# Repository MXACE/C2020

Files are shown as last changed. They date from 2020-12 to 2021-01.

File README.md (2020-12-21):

# C2020
Christmas Project and for the JLCPCB contest (https://jlcpcb.com).

The project was made with altium.
It is a christmas tree with a holder that you can break of the pcb.
The ic on this pcb is designed the way, that they look like they were presents under the.

On the backside of the tree there will be mounted some reverse RGB LEDs that are controlled by a RGB driver over i2c.

I made this for some friends and familymember as a gift.

You can view some pictures of the pcb if you open schematics.pdf. I didnt received the pcb yet.

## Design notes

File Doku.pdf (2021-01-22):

TBZ | Marco Stauber

# Weihnachtsprojekt

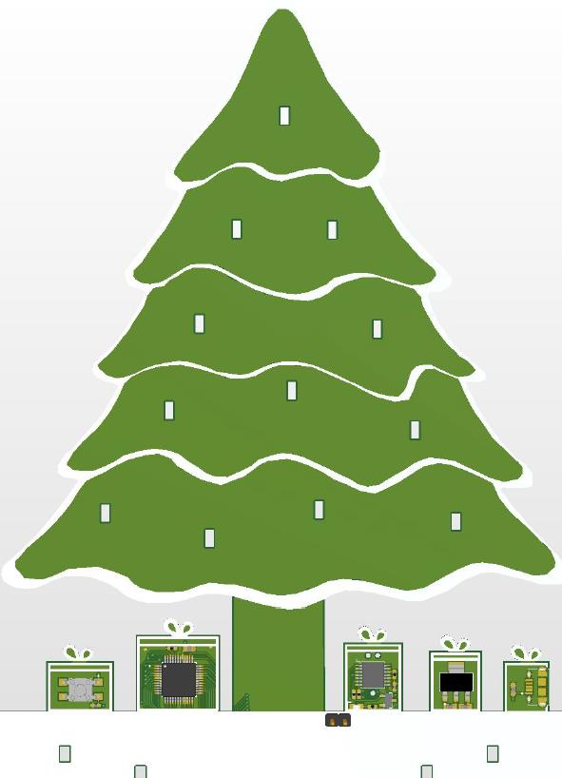
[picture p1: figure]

## Inhaltsverzeichnis

## Idee

Ich wollte für Weihnachten 2020 ein spezielles Geschenk an Familie und Bekannte machen. Eins das von mir kommt. Gleichzeitig hat JLCPCB einen Wettbewerb gestartet, bei dem man ein PCB designen muss das einen Festlichen Stil hat. Dabei kam ich auf die Idee einen Weihnachtsbaum zu zeichnen unter welchem sich Geschenke befinden und darin sind die grossen Bauteile. Als nächstes entschied ich mich dafür dass LEDs die
Weihnachtsbaumkugeln simulieren sollten.

## Umsetzung

### Schema

Ich habe mir eine Skizze vom Baum gemacht und überlegt wie viele und wie ich die LEDs verteilen will. Optimal sind es bei dieser Grösse 12. Um auch schöne Animationen zu gestalten brauchte ich RGB LEDs und für den optischen Pluspunkt Reverse LEDs, die durch kleine Löcher im PCB, durchscheinen können.

Um nicht Tausend RGB Treiber haben zu müssen, nahm ich gleich einen mit 36 Kanälen. Dieser kann man über I2C ansteuern. Er hat für jeden Kanal ein PWM Register und noch weitere Einstellungen.
Das Interessante an diesem Bauteil ist, dass der Pin für die Slave-Adresse 2 Bits entsprechen.

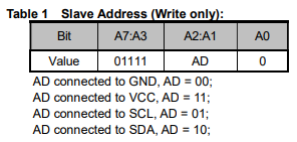
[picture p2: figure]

Das PCB wird über einen USB Mikro Anschluss versorgt. Die heutigen Geräte haben meistens einen USB C Anschluss. Zunächst wollte ich auch eine USB C Buchse nehmen, aber da meine Verwandtschaft eher noch ältere Geräte haben, haben sie auch noch ein paar alte USB Mikro Kabel herumliegen.
Über einen Linearregler kriegt man eine 3.3V Speisung.

Einen Taster ermöglicht das Wechseln zwischen verschiedenen Animationen. Jedoch habe ich nicht gesehen dass der gleiche Pin vom Mikrokontroller, an dem er angeschlossen ist, auch BOOT0 ist. Dieser Fehler hat mich einige Nerven gekostet und konnte es später aber herausfinden. Parallel zum Stütz-Kondensator gibt es jetzt einen 10kOhm Widerstand.

Da ich fast nichts steuern muss, brauchte ich nur einen ganz kleinen Mikrokontroller, welcher ein TSSOP-14 Gehäuse hat. Programmieren tue ich ihn über einen TagConnect Footprint welcher ich zum ersten Mal benutze. Zusätzlich gibt es noch ein LED welches mir noch über das Programm, einen Status geben kann.

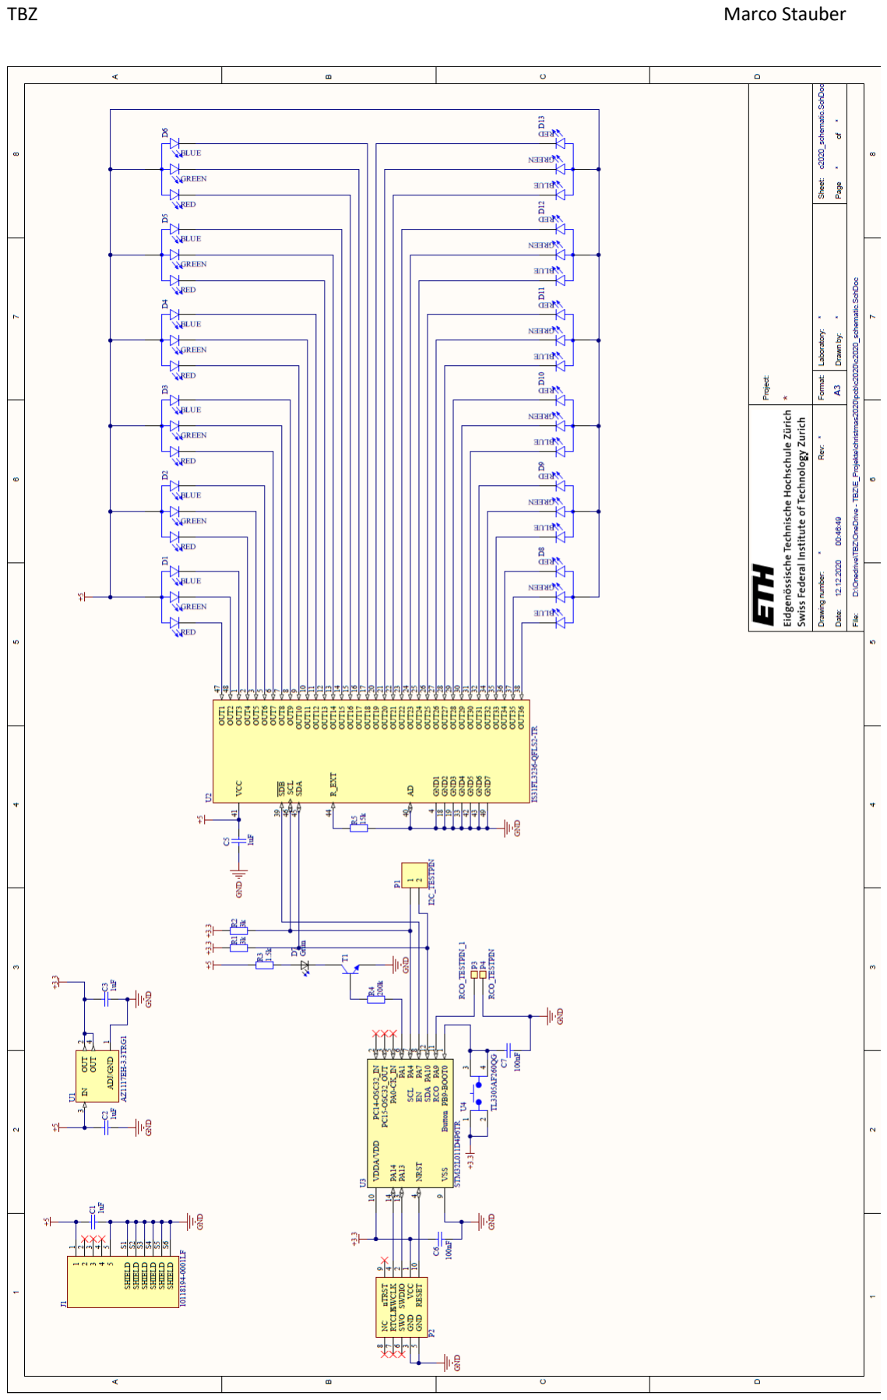
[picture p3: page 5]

### Layout

Der grosse Aufwand hier war der Weihnachtsbaum selber. Ich habe mir irgendein Vektorbild von einem Weihnachtsbaum auf Google gesucht und das in Altium importiert. Danach habe ich den Boardrand auf den Baum angepasst. Die Schneespuren, die auf dem Bild waren, habe ich mit dem Polygon nachgefahren und dann auf das Silkscreenlayer verschoben.

Auf diesem Print ist der Baumstamm nicht das unterste Teil. Sondern es gibt noch einen Boden auf dem die Geschenke sich befinden und Leiterbahnen sich verstecken. Der ganze Boden ist mit dem Silkscreen bedeckt.
Damit der Baum auch steht platzierte ich Löcher in einer Linie auf die ganze Breite, damit ich nachher dieses Stück abbrechen kann und überkreuz in den Boden des Baums stecken kann.

Auf der Rückseite des Baumes sind die LEDs versteckt und die grossen Bauteile die grossen Bauteile. Damit man keine Löcher von Vias im Baum hat, habe ich alle unter dem Silkscreen versteckt.
Die Leiterbahnen des LED Treibers musste ich sehr eng ziehen, da fast kein Platz vorhanden ist.
Der TagConnect Anschluss befindet sich auf der Rückseite.

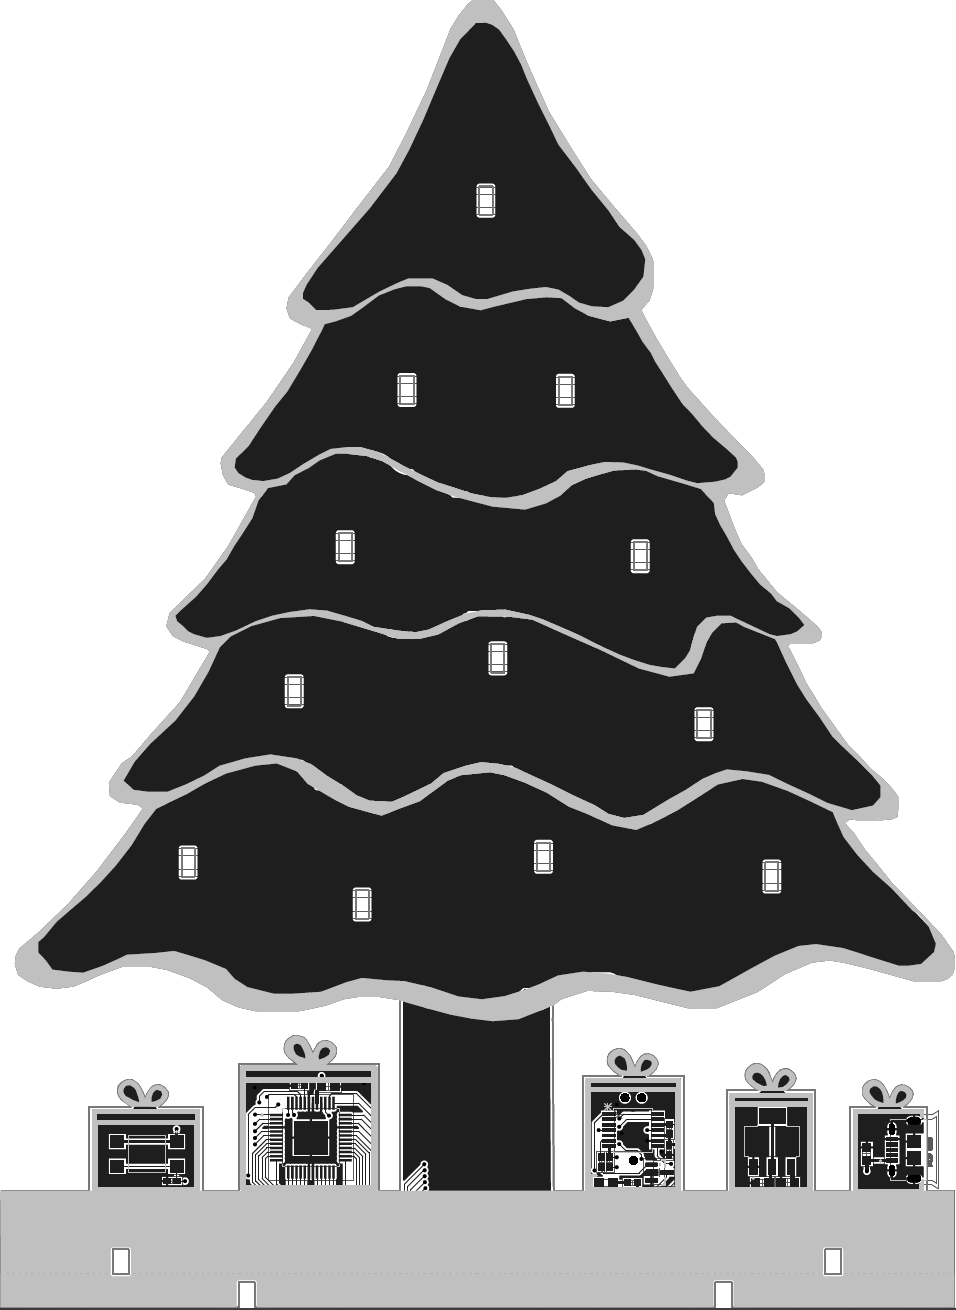
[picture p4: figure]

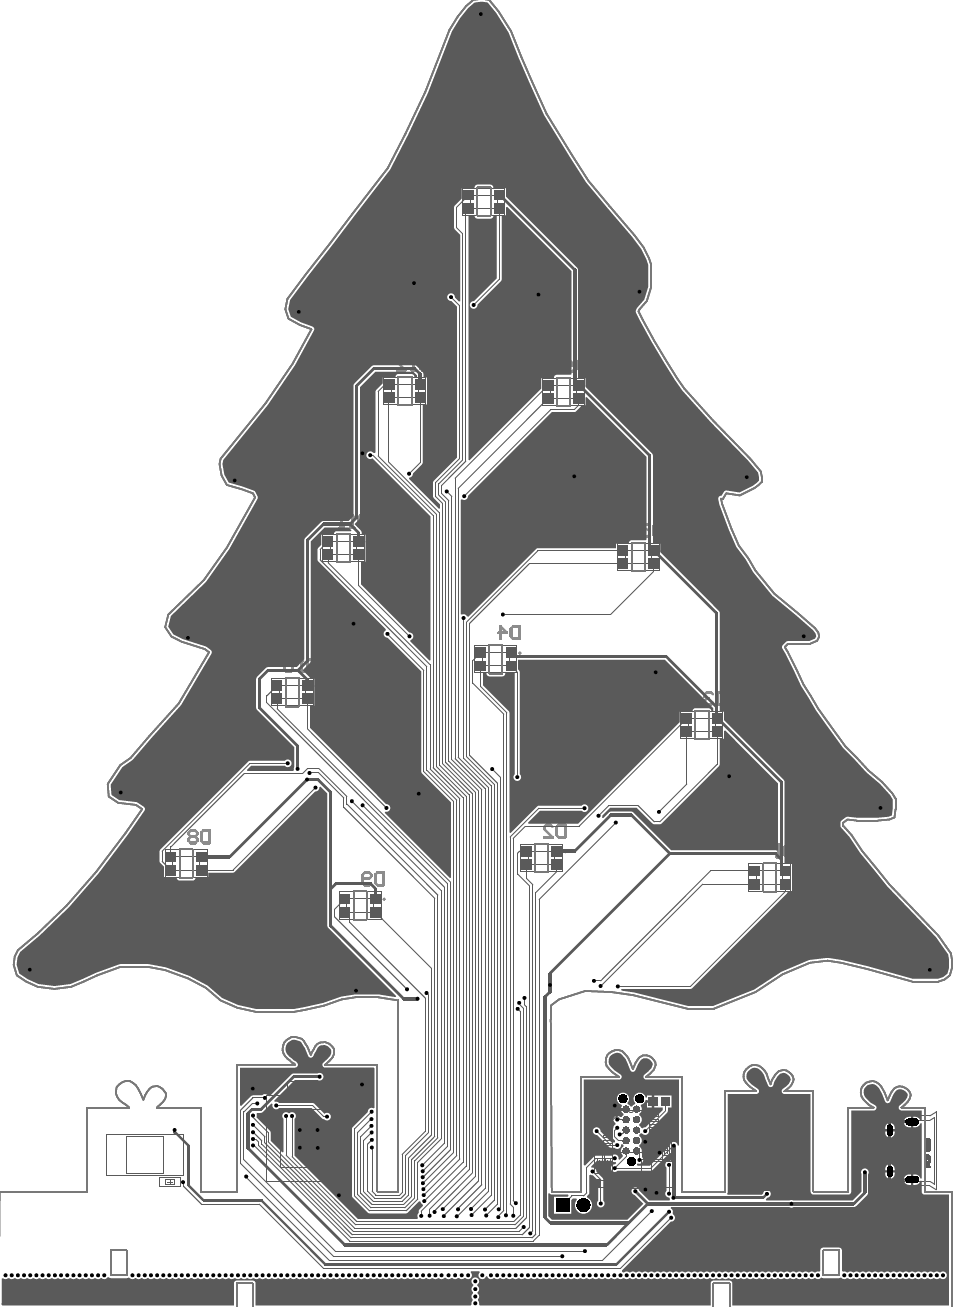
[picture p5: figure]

## Programm

Ich hatte zuerst das Problem dass ich den LED Treiber nicht ansprechen konnte. Es lag daran das der Enable-Pin gar nicht Active Low ist, so wie es im Schema gekennzeichnet ist.

Für den Treiber habe ich einzelne Funktionen, bei denen die Slave-Adresse schon fest vorprogrammiert ist.
Register und die Slaveadresse wurden mit Defines bestimmt. Genauso die zugehörigen Register zu den RGB LEDs.

Das LED unterhalb des Mikrokontrollers zeigt den Kommunikationsstatus der I2C Leitung. Blinkt sie einmal, kann er den LED Treiber ansprechen. Bei zweifachen Blinken kann er es nicht.
Danach gehen die LEDs an.

Es gibt fünf verschiedene Animationen:

1: RGB
Jeweils vier LEDs haben eine definierte Farbe (RGB). Jede LED hat eine eigene Zählvariable die einen Sinus-Lookuptable folgt. Damit hat man ein schönen blinken

2: Gold
Alle LEDs leuchten in einem Grün-Rot Gemisch, welches ähnlich aussieht wie Gold;

3: Rot
Alle LEDs leuchten rot.

4: Grün
Alle LEDs leuchten grün.

5: Blau
Alle LEDs leuchten blau.

Der Taster habe ich an einen EXTI Eingang gelegt um ihn nachher per Interrupt abzufragen.
Dies erlaubt es mir ununterbrochen die Animationen auszuführen ohne ständig nach dem Taster zu fragen.

## Fazit

Ich konnte für eine lange Zeit den Mikrokontroller nicht programmieren. Einerseits da Boot0 nicht mit Ground verbunden wurde und der STlink/v2 nicht auf dem neusten Stand war.

Zuhause habe ich nicht Möglichkeit kleinere Sachen einzulöten. Daher hatte ich sehr Mühe mit dem LED Treiber einlöten. Es kann sein das einzelne Farben von LEDs nicht funktionieren.

Das Projekt hat mir ziemlich Spass gemacht, da es Designtechnisch eine Herausforderung war.
Ich war nicht sicher ob die Kanten und Ecken der Schlaufen oder der Baum an sich gut herauskommen.

Bei diesem Projekt konnte ich viel lernen, darunter konnte ich auch lernen wie ich einen EXTI-Interrupt und I2C der HAL Library verwende. Nun weiss ich auch das beim

Alle Dateien findet man in diesem GitHub: https://github.com/MXACE/C2020

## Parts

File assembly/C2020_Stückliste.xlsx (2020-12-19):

 | Name | Desc | Partnumber | amount | price/p |  | total
Digikey | IS31FL3236-TQLS2 | LED Driver | 706-1361-ND | 1 | CHF 2.07 |  | CHF 2.07 | x
 | TL3305AF260QG | Taster | EG5353CT-ND | 1 | CHF 0.16 |  | CHF 0.16 | x
 | 10118194-0001LF | usb micro | 609-4618-1-ND | 1 | CHF 0.41 |  | CHF 0.41 | x
 | 156120M173000 | rgb led | 732-13408-1-ND | 12 | CHF 0.67 |  | CHF 8.02 | x
 | STM32L011D4P6 | uC | 497-STM32L011D4P6CT-ND | 1 | CHF 1.75 |  | CHF 1.75
 |  |  |  |  |  |  | CHF 0.00
 | TC2050-IDC-NL | tag connect | TC2050-IDC-NL-ND | 1 | CHF 35.49 |  | CHF 35.49
 | TC2050-ARM2010 | adapter | TC2050-ARM2010-ND | 1 | CHF 34.07 |  | CHF 34.07
 |  |  |  |  |  |  | CHF 0.00
 |  |  |  |  |  |  | CHF 0.00
 |  |  |  |  |  |  | CHF 0.00
 | SFH11-PBPC-D10-ST-BK |  |  |  |  |  | CHF 0.00
 | SFH11-PBPC-D10-RA-BK |  |  |  |  |  | CHF 0.00
 |  |  |  |  |  |  | CHF 0.00
 |  |  |  |  |  |  | CHF 0.00
 |  |  |  |  |  |  | CHF 0.00 |  | CHF 12.41 | CHF 131.59
 |  |  |  |  |  | e?
JLC | CL10A105KB8NNNC | 1uf,0603 | C15849 | 4 | $0.01 |  | $0.05
 | CL05B104KO5NNNC | 100nf,0402 | C1525 | 3 | $0.003 |  | $0.01
 | 0402WGF1502TCE | 15k,0402 | C25756 | 1 | $0.0012 |  | $0.0012
 | 0402WGF2001TCE | 1.8k,0402 | C4109 | 2 | $0.0012 |  | $0.0024
 | S8050 | transistor npn | C2146 | 1 | $0.02 |  | $0.02
 | 19-217/GHC-YR1S2/3T | led green | C72043 | 1 | $0.04 |  | $0.04
 | 0402WGF1501TCE | 1.5k,0402 | C25867 | 1 | $0.0011 |  | $0.0011
 | 0402WGF2003TCE | 200k,0402 | C25764 | 1 | $0.001 |  | $0.001
 | AZ1117EH-3.3TRG1 | 3.3V | C108494 | 1 | $0.09 | $3.00 | $0.09
 |  |  |  |  |  |  | $0.00
 |  |  |  |  |  |  | $0.00
 |  |  |  |  |  |  | $0.00
 |  |  |  |  |  |  | $0.00
 |  |  |  |  |  |  | $0.00
 |  |  |  |  |  |  | $0.00
 |  |  |  |  |  |  | $0.00
 |  |  |  |  |  |  | $0.00
 |  |  |  |  |  |  | $0.00
 |  |  |  |  |  |  | $0.00
 |  |  |  |  |  |  | $0.00
 |  |  |  |  |  |  | $0.00
 |  |  |  |  |  |  | $0.00
 |  |  |  |  |  |  | $0.00 |  | $0.20 | $4.02

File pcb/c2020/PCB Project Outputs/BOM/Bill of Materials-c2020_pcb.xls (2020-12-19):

Comment | Description | Designator | Footprint | LibRef | Manufacturer | Manufacturer Part Number | Note | Quantity | Supplier | Supplier Part Number | Library Reference
1uF | capacitor | C1, C2, C3, C5 | CAP_0603i_1608m -N | Cap |  |  |  | 4
100nF | capacitor | C6, C7 | CAP_0402i_1005m -N | Cap |  |  |  | 2
156120M173000 | Red, Green, Blue (RGB) 624nm Red, 525nm Green, 470nm Blue LED Indication - Discrete 2V Red, 3.3V Green, 3.3V Blue 1206 (3216 Metric) | D1, D2, D3, D4, D5, D6, D8, D9, D10, D11, D12, D13 | LED_156120M173000 | 156120M173000 |  |  |  | 12
Grün | LED; SMD; 0603; grün; 35mcd; 1.6x0.8x0.55mm; 130Â°; 2Ã·2.V; 20mA | D7 | *0603 | LTST-C191KGKT |  |  |  | 1
10118194-0001LF | USB - micro B USB 2.0 Receptacle Connector 5 Position Surface Mount, Right Angle; Through Hole | J1 | AMPHENOL_10118194-0001LF | 10118194-0001LF |  |  |  | 1
I2C_TESTPIN | Header, 2-Pin | P1 | HDR1X2 | Header 2 |  |  |  | 1
Tag-Connect TC2050-IDC-NL-No pin assigned | 10-pin pogo pin programing port | P2 | TAG-CONNECT TC2050-IDC-NL 10-Pin | Tag-Connect TC2050-IDC-NL-No pin assigned |  |  |  | 1
RCO_TESTPIN_1 | Single Pad or Testpoint | P3 | Pad_0603 | Pad |  |  |  | 1
RCO_TESTPIN | Single Pad or Testpoint | P4 | Pad_0603 | Pad |  |  |  | 1
3k | Resistor | R1, R2 | RES_0402i_1005m -N | Res |  |  |  | 2
1.5k | Resistor | R3 | RES_0402i_1005m -N | Res |  |  |  | 1
200k | Resistor | R4 | RES_0402i_1005m -N | Res |  |  |  | 1
15k | Resistor | R5 | RES_0402i_1005m -N | Res |  |  |  | 1
BJT NPN | NPN Bipolar Transistor | T1 | SOT23-N | BJT NPN |  |  | Check footprint as it may differ | 1
AZ1117EH-3.3TRG1 | Linear Voltage Regulator IC 1 Output 1A SOT-223 | U1 | SOT230P700X180-4N | AZ1117EH-3.3TRG1 |  |  |  | 1
IS31FL3236-QFLS2-TR | LED Driver IC 36 Output Linear IÂ²C Dimming 38mA 44-QFN (5x5) | U2 | QFP50P900X900X160-48N | IS31FL3236-QFLS2-TR |  |  |  | 1
STM32L011D4P6TR | No Description Available | U3 | TSSOP14 | STM32L011D4P6TR |  |  |  | 1
TL3305AF260QG | Tactile Switch SPST-NO Top Actuated Surface Mount | U4 | SW_TL3305AF260QG | TL3305AF260QG |  |  |  | 1

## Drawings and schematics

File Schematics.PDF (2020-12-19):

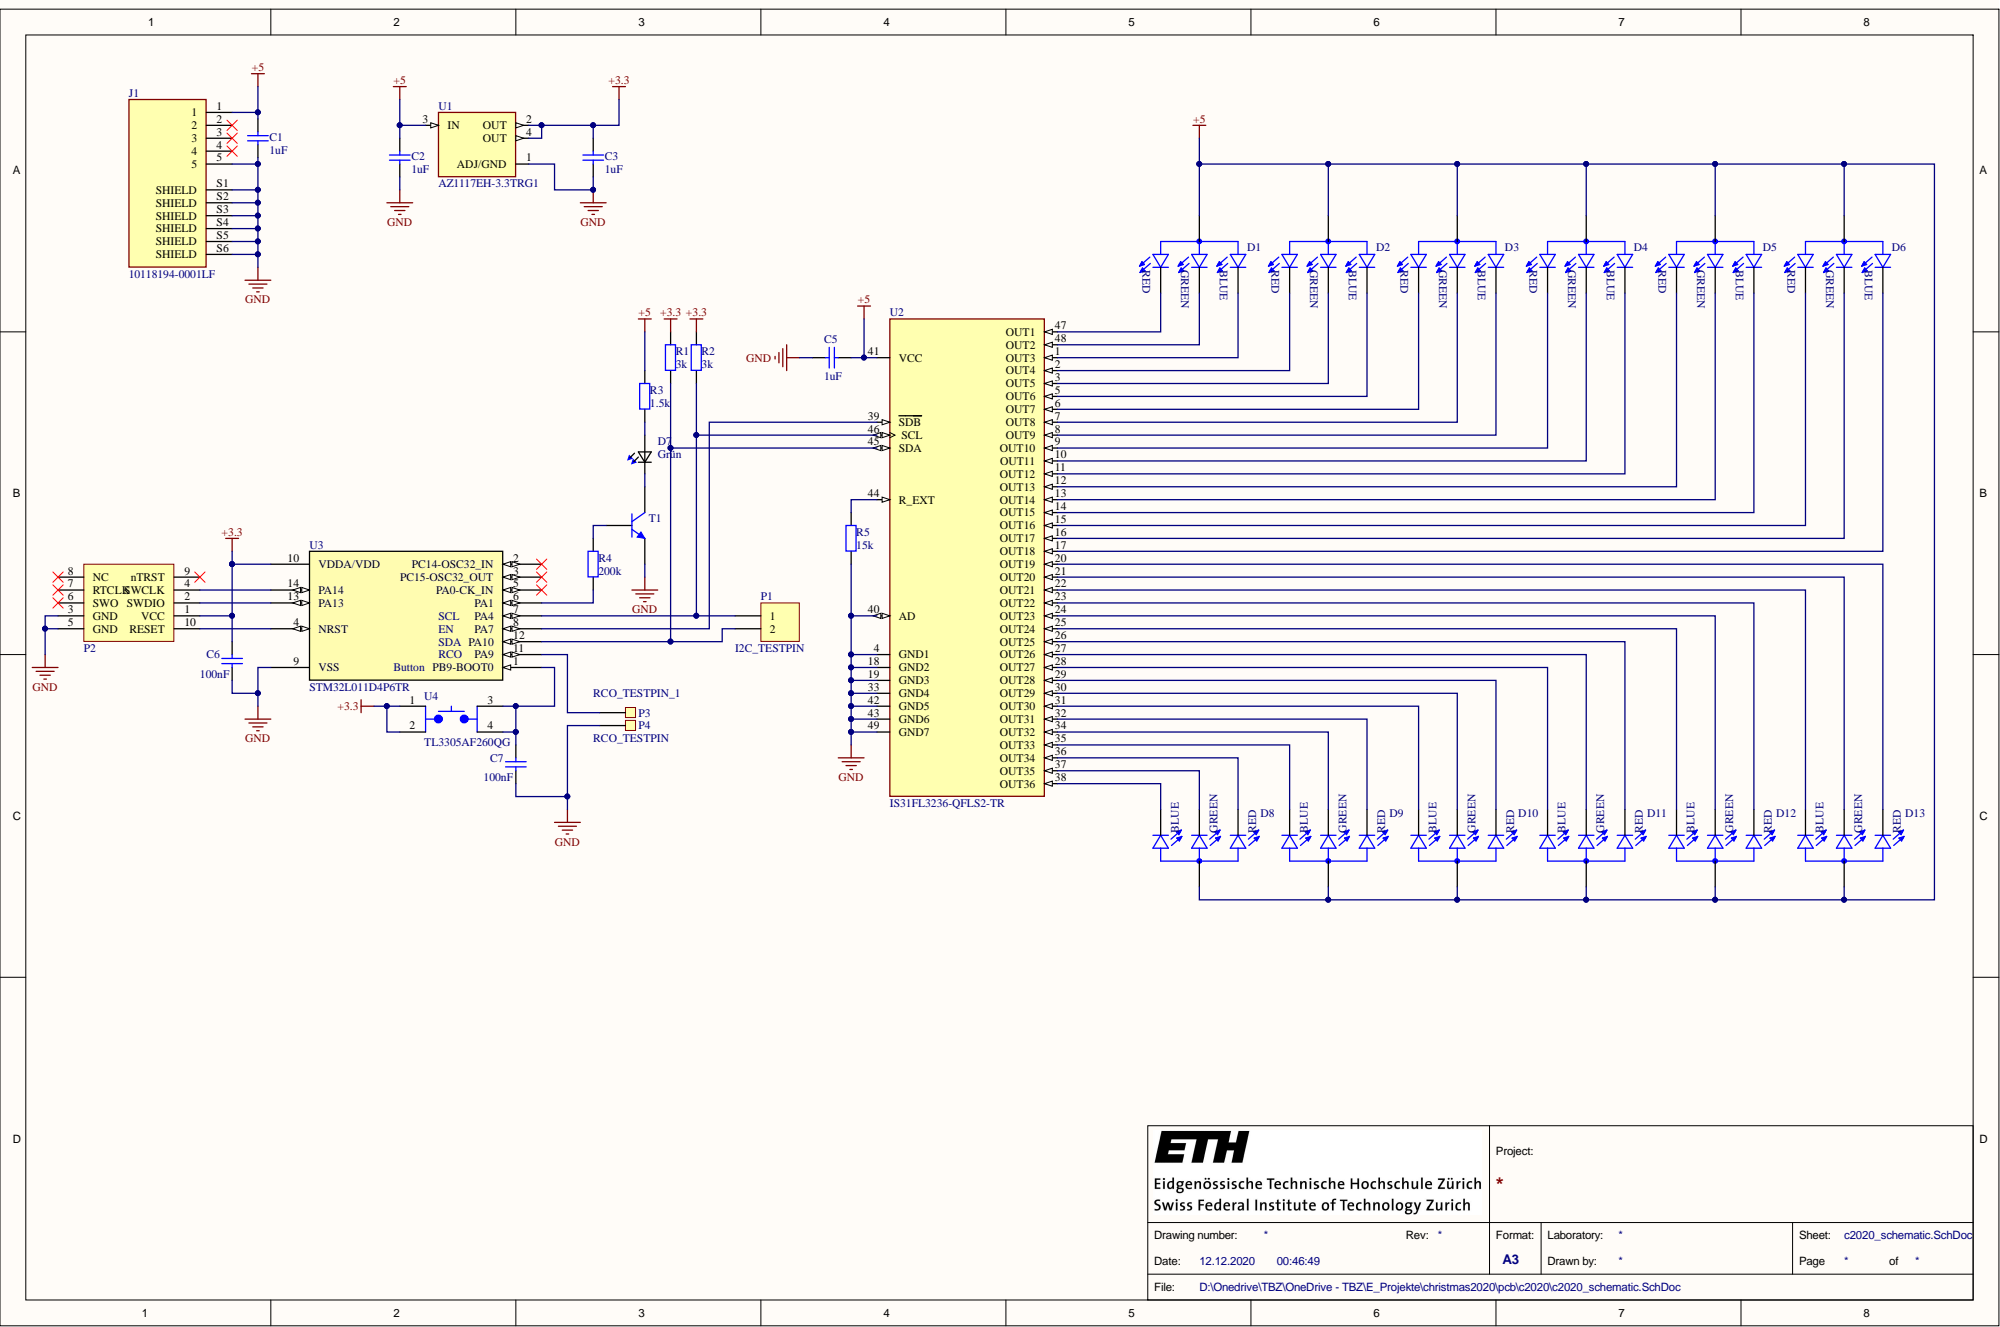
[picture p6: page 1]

SCL 46 | 8
SDA 45 | 9

n | | R_EXT 44

GND3 19

GND5 42

Pro jec t : *

Dra w i n g n u m ber : * Rev: * Dat e : 12. 12. 202 0 00: 46: 4 9 | For m a t : A 3 | Labor ato ry : * Dra w n b y : * | S SchDo h eet : c20 20_ schemat ic. c Pag e * o f *

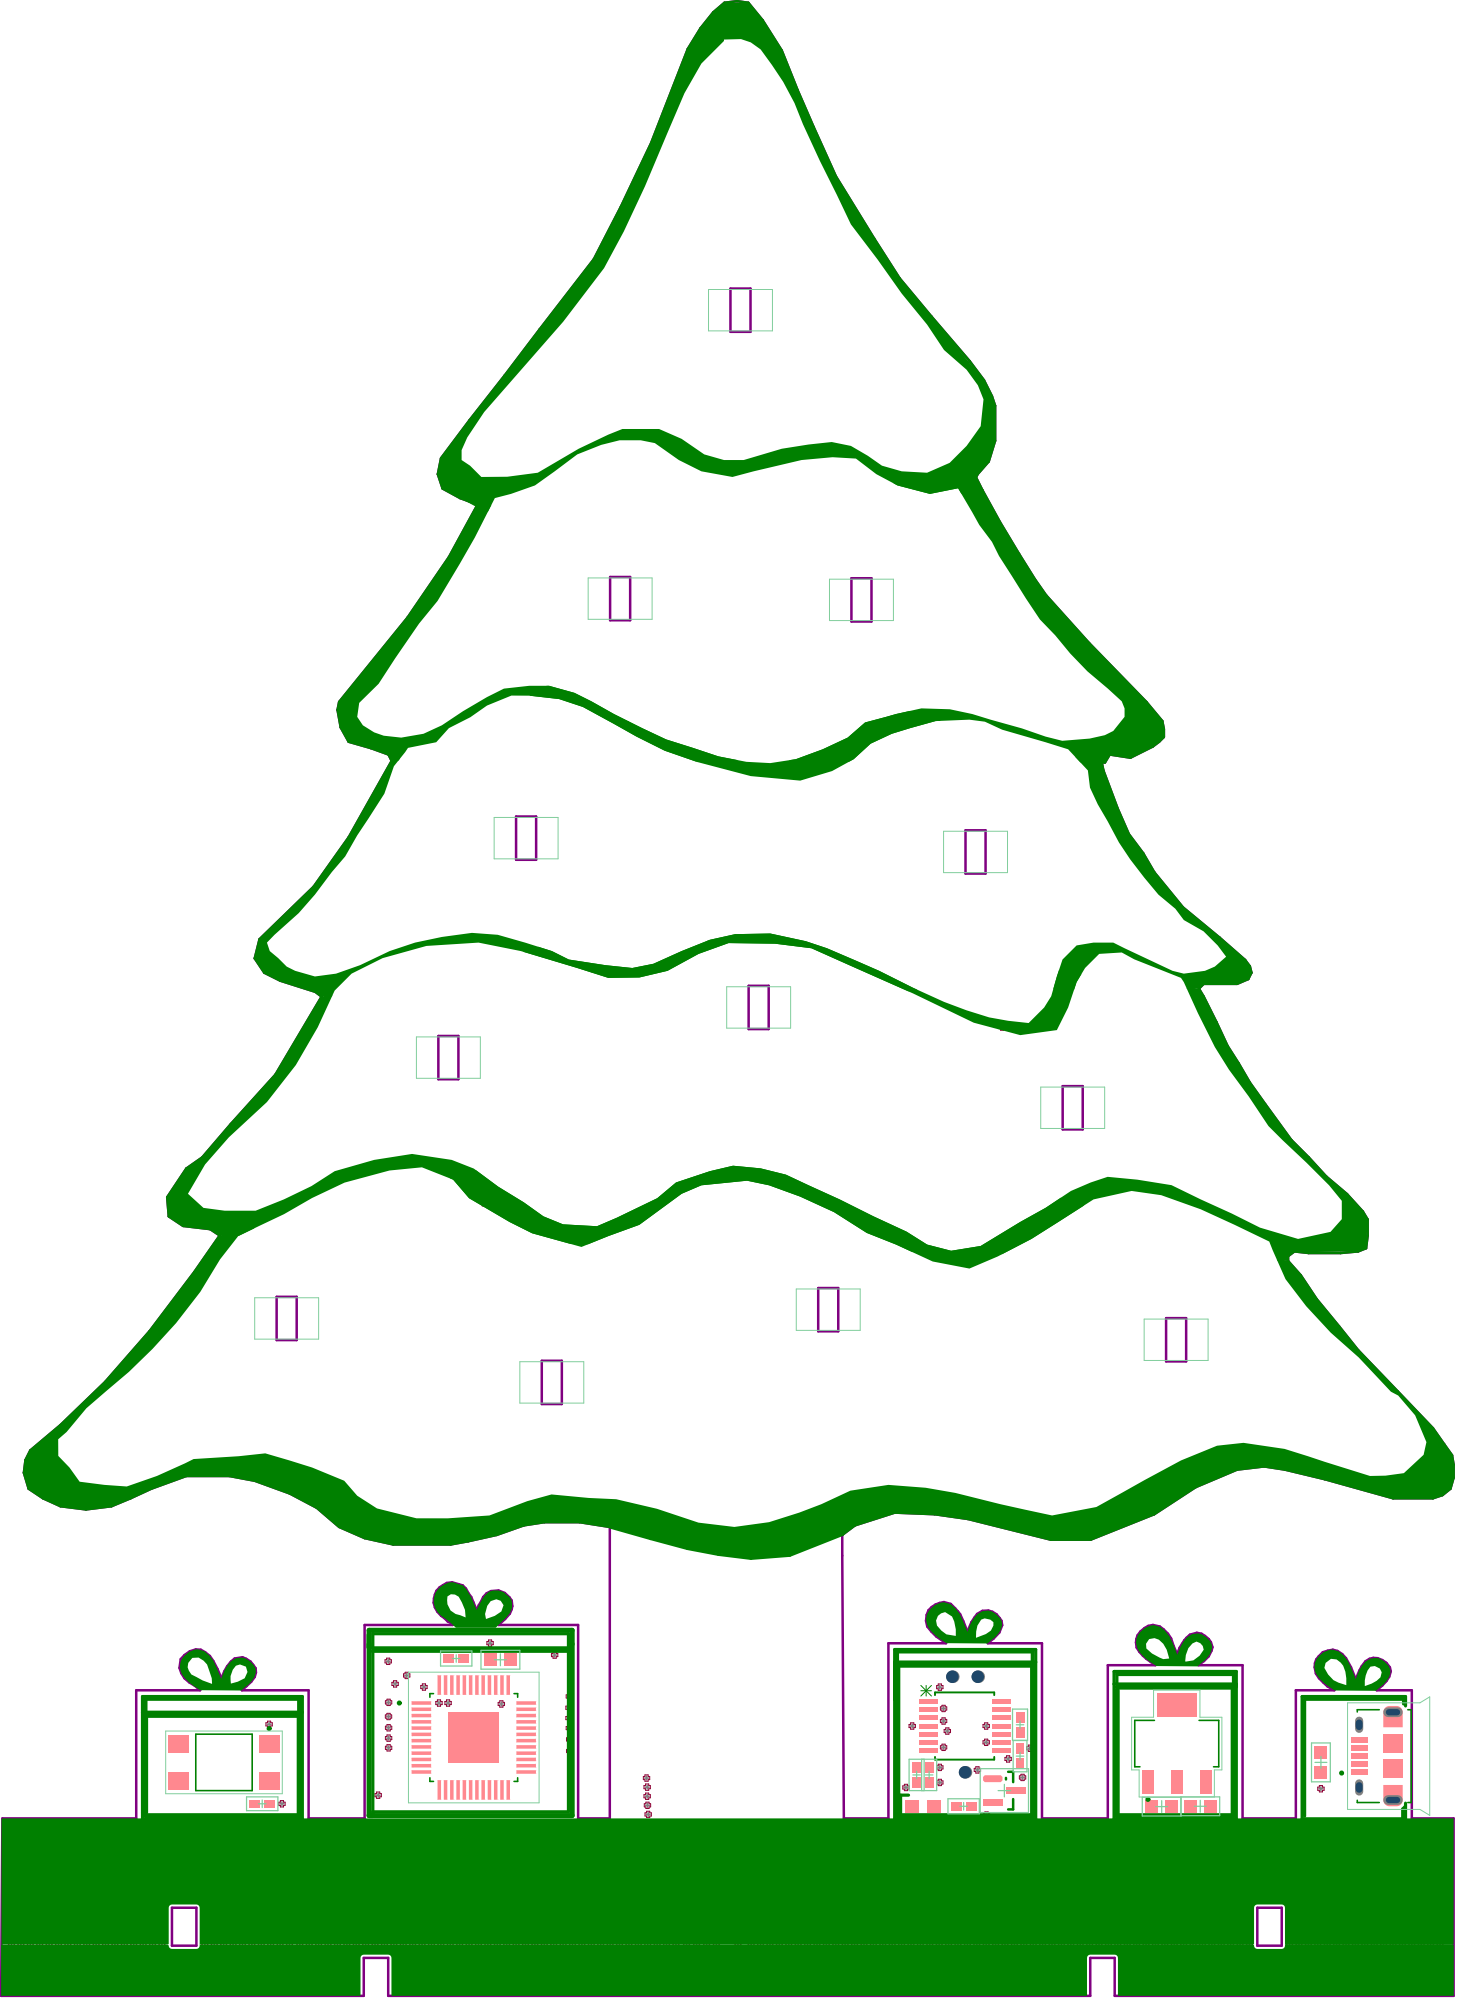
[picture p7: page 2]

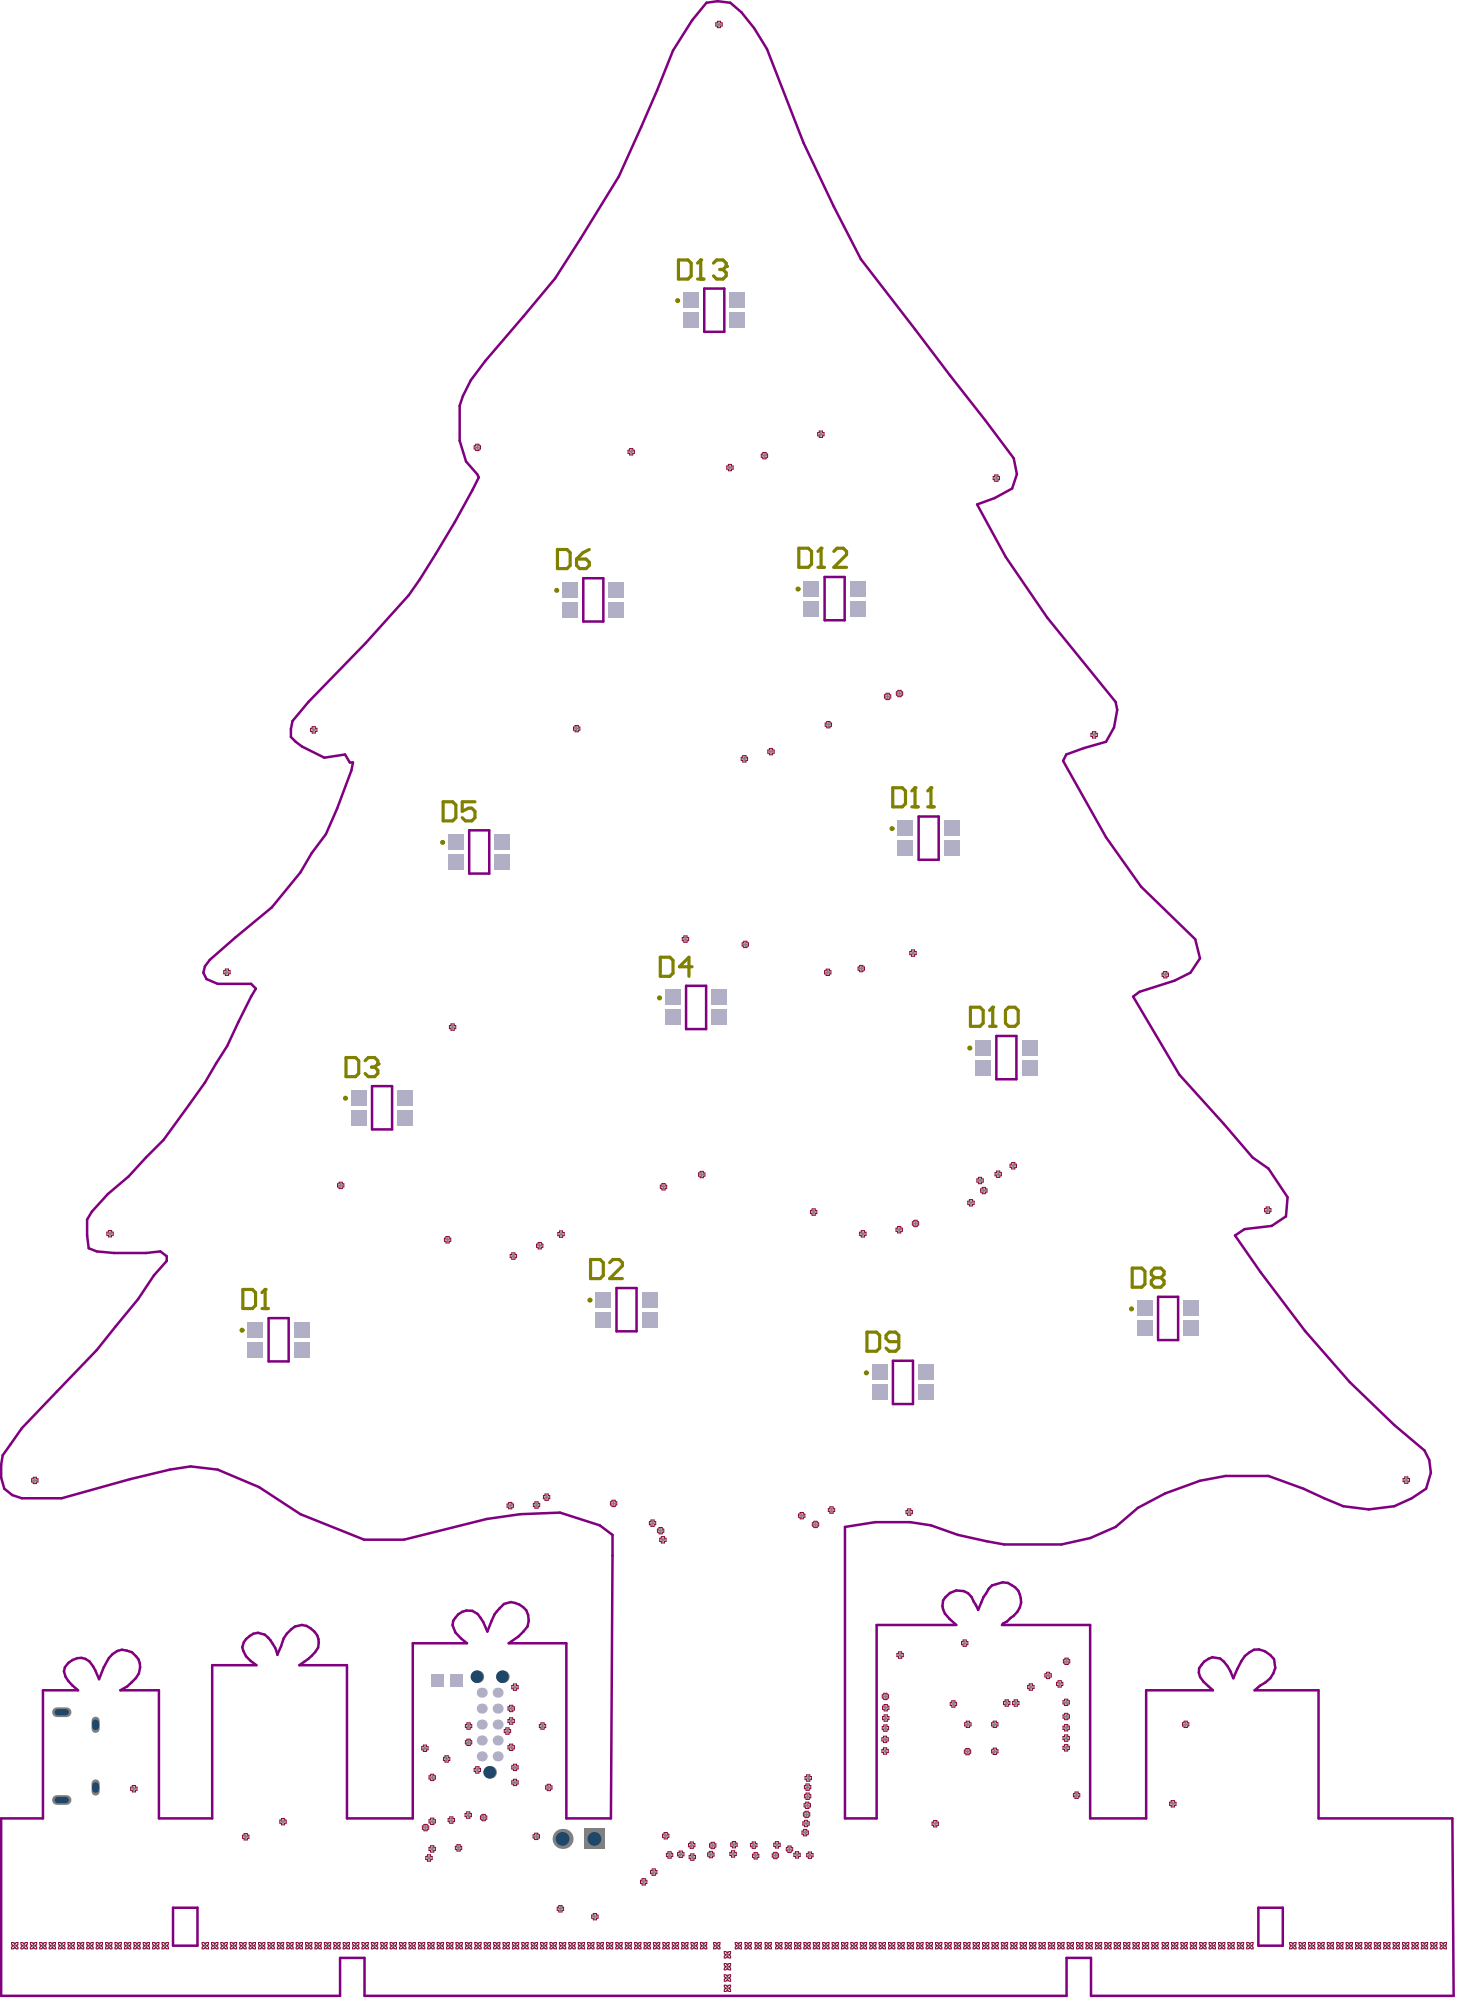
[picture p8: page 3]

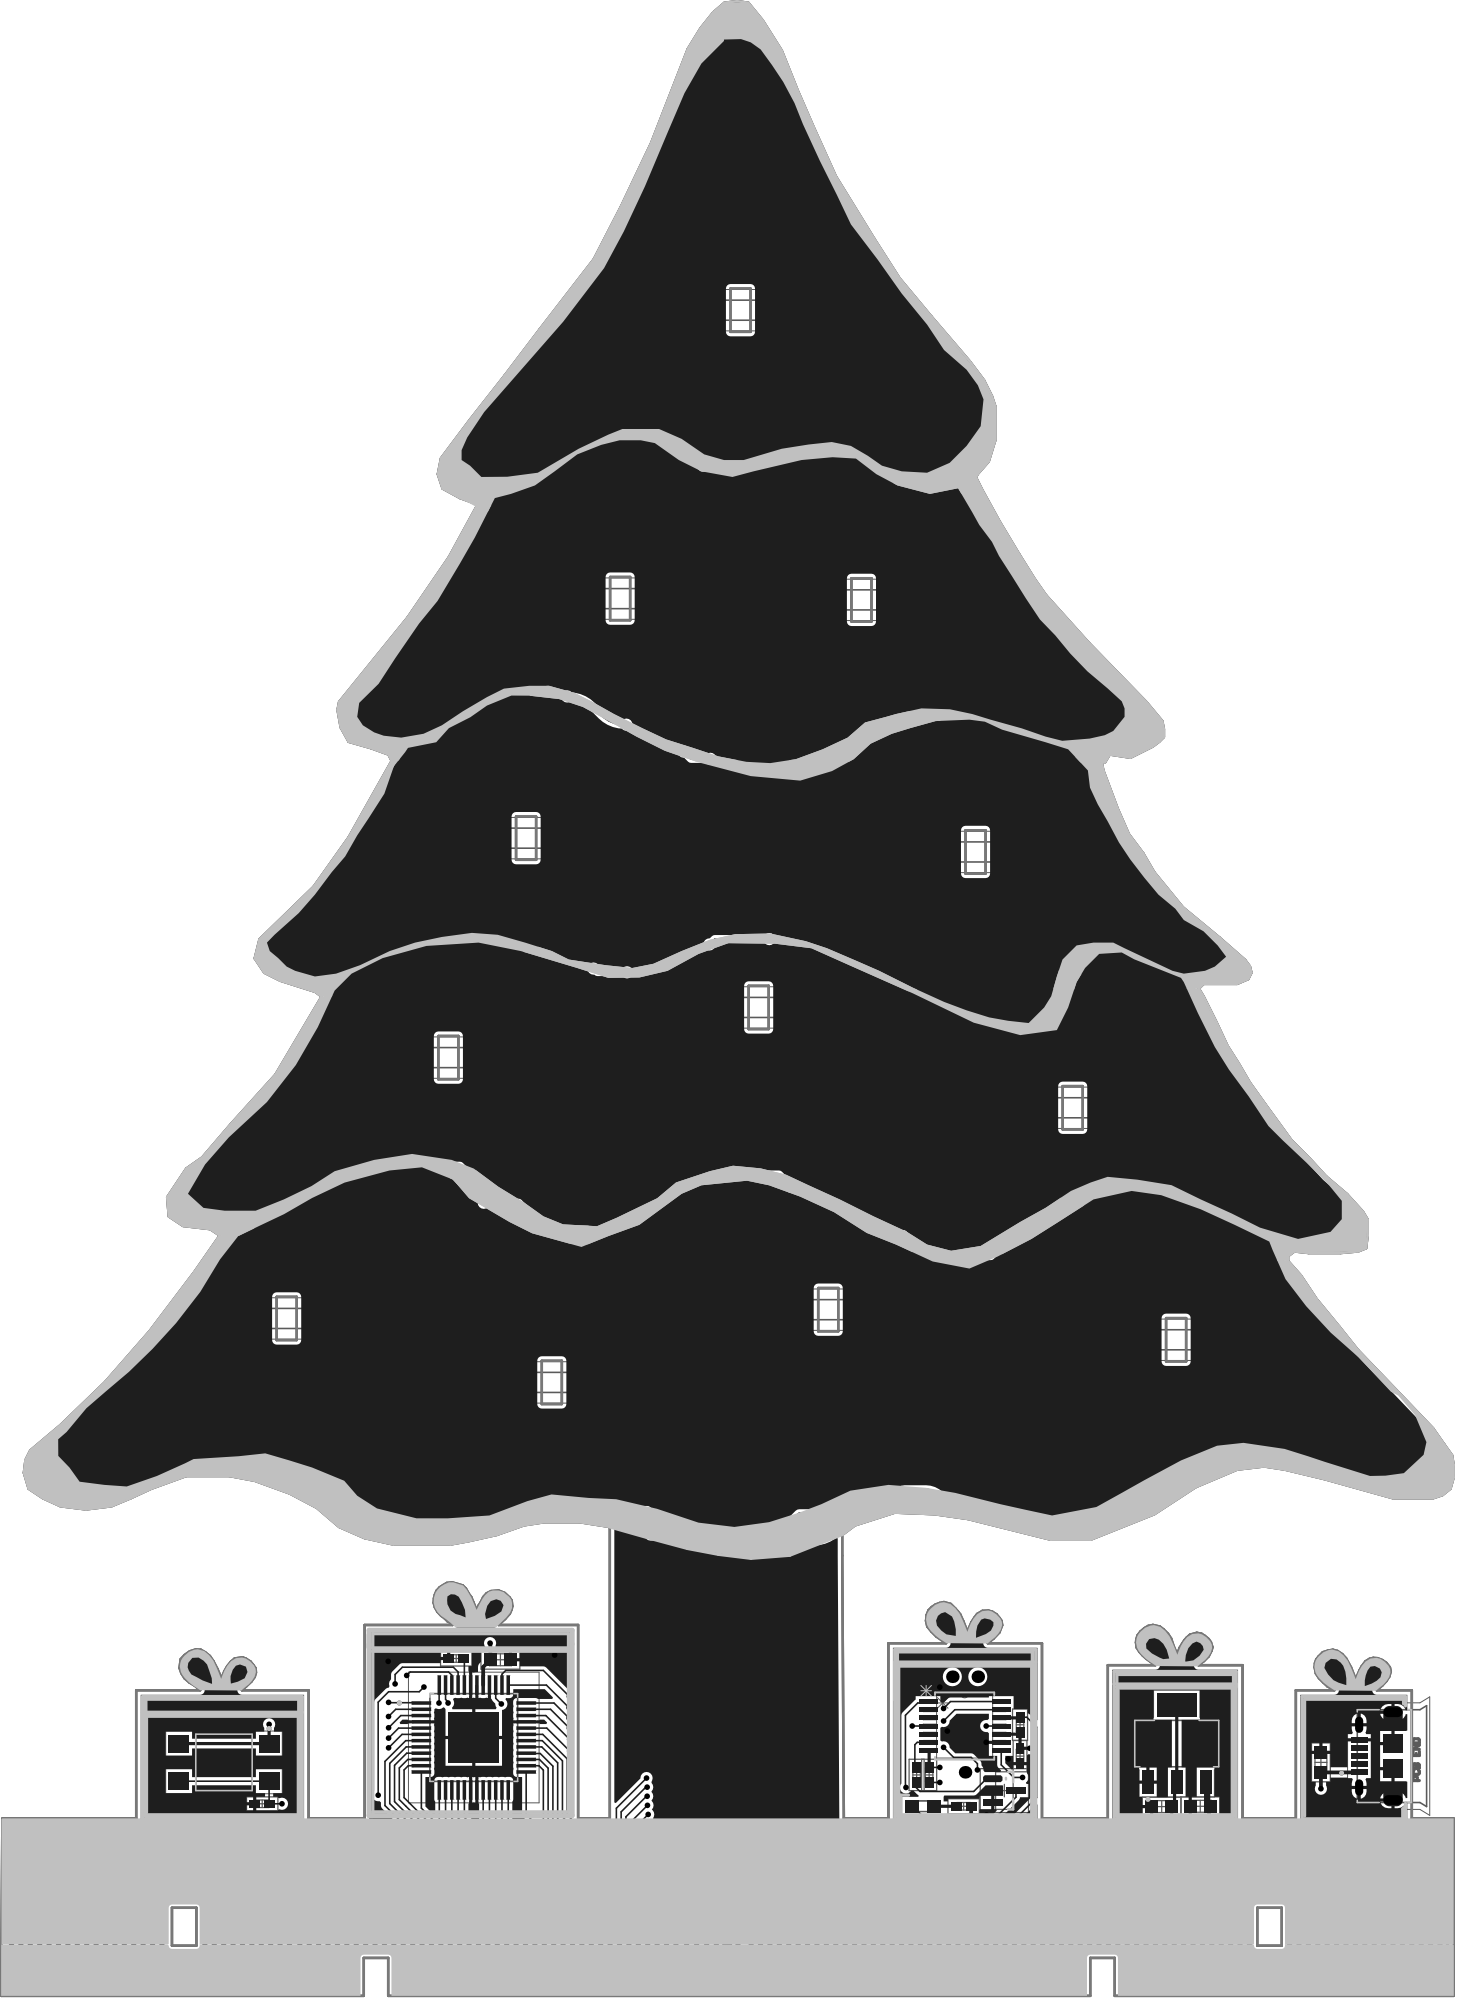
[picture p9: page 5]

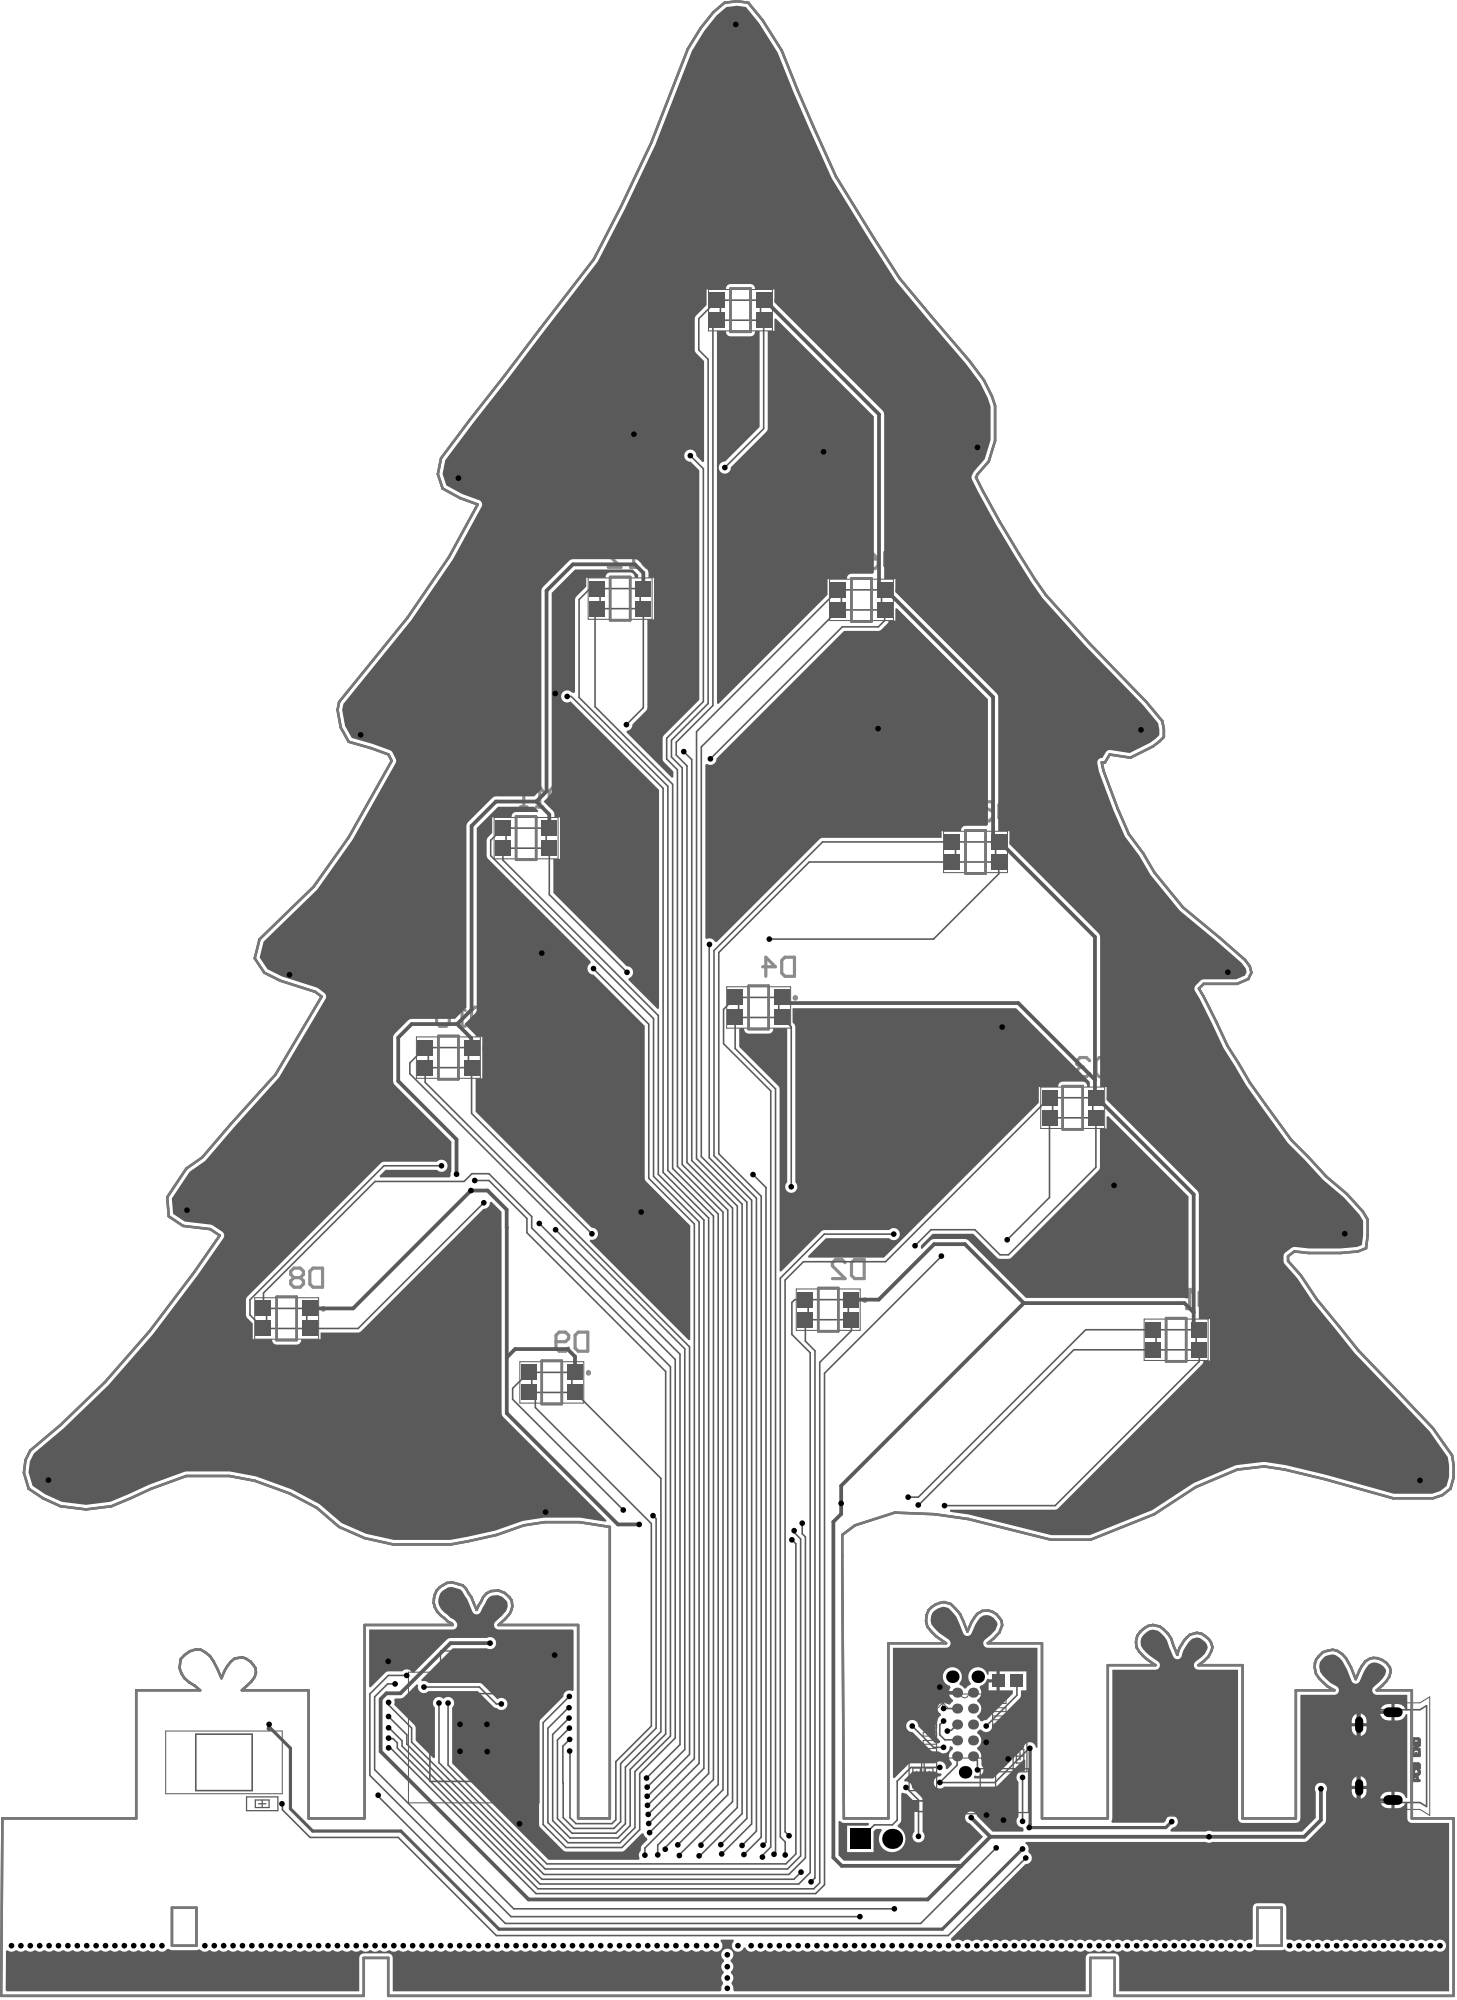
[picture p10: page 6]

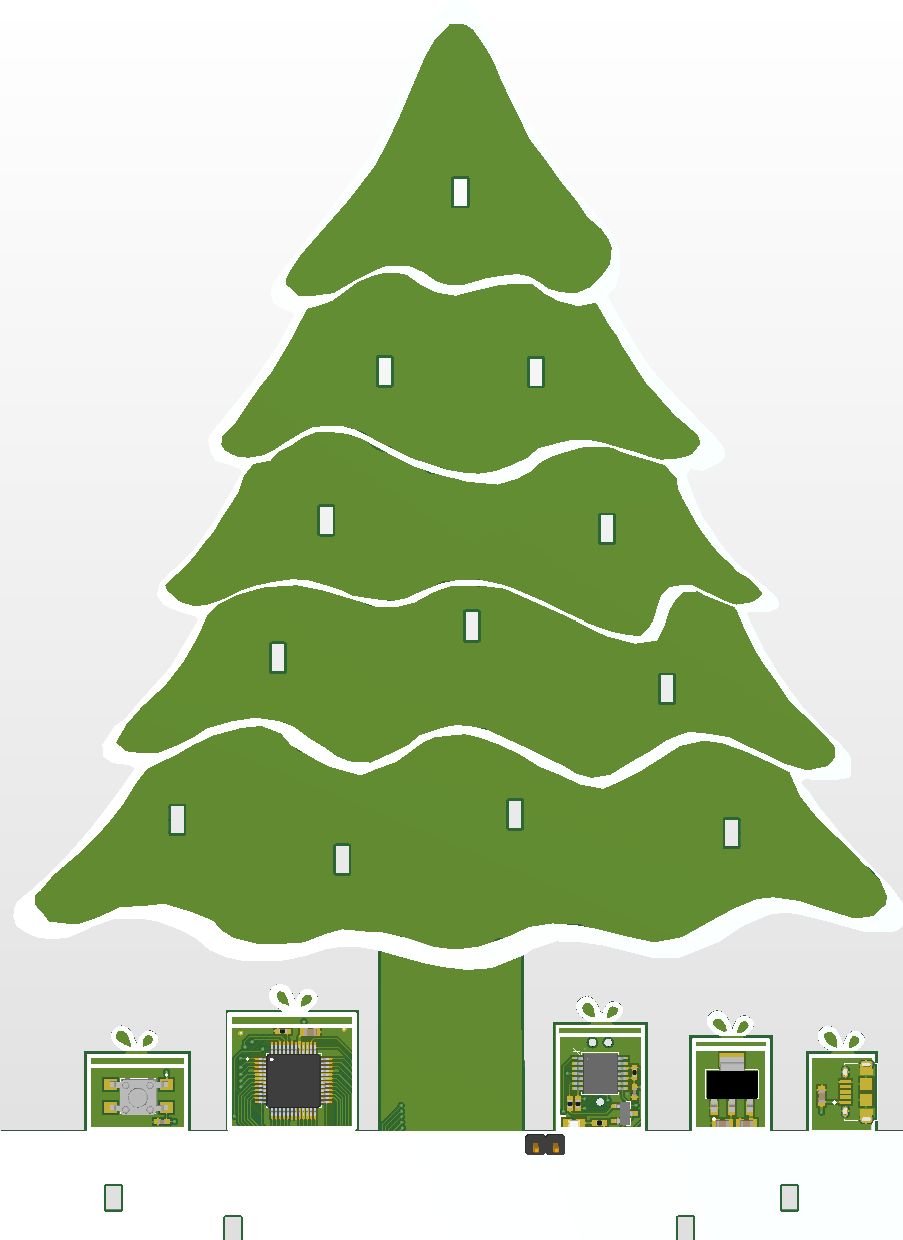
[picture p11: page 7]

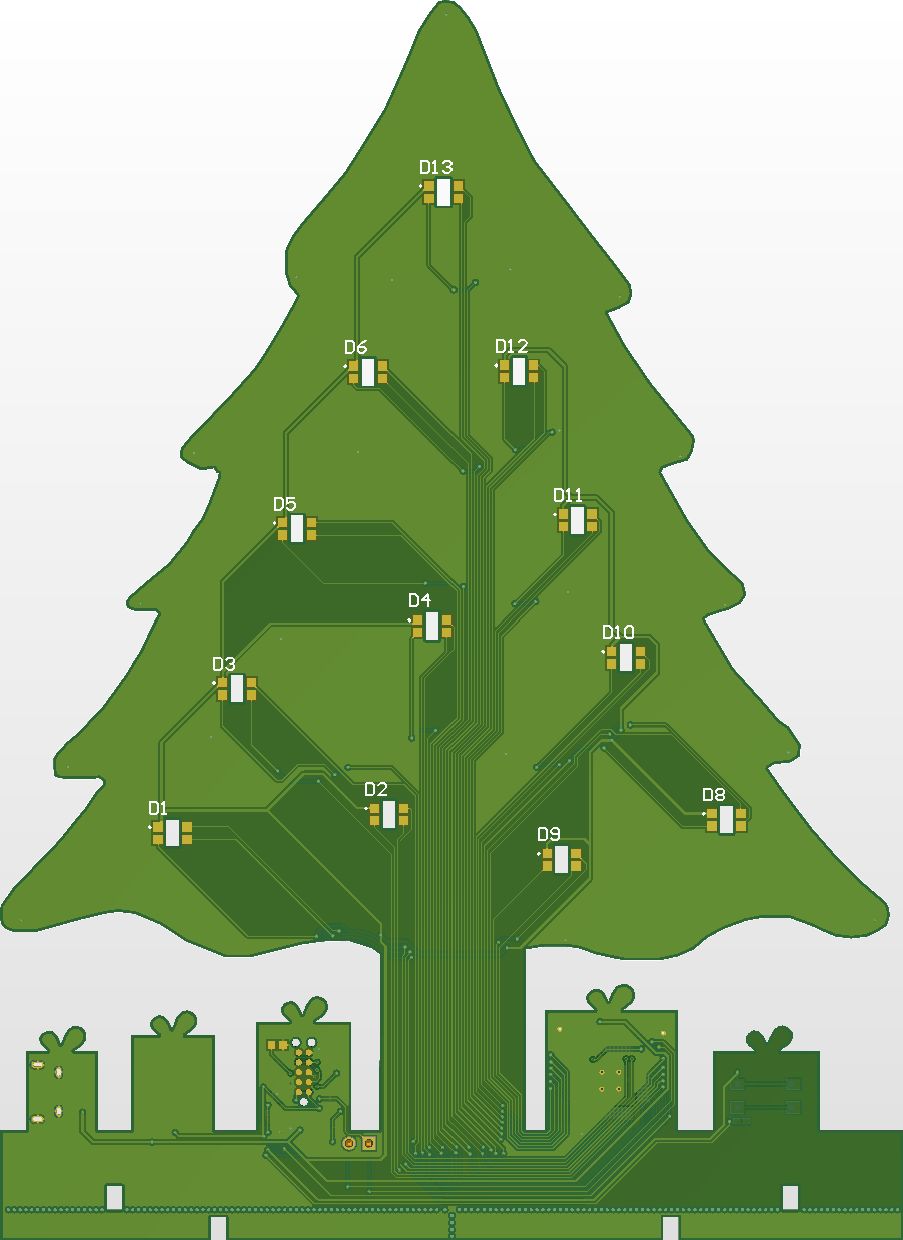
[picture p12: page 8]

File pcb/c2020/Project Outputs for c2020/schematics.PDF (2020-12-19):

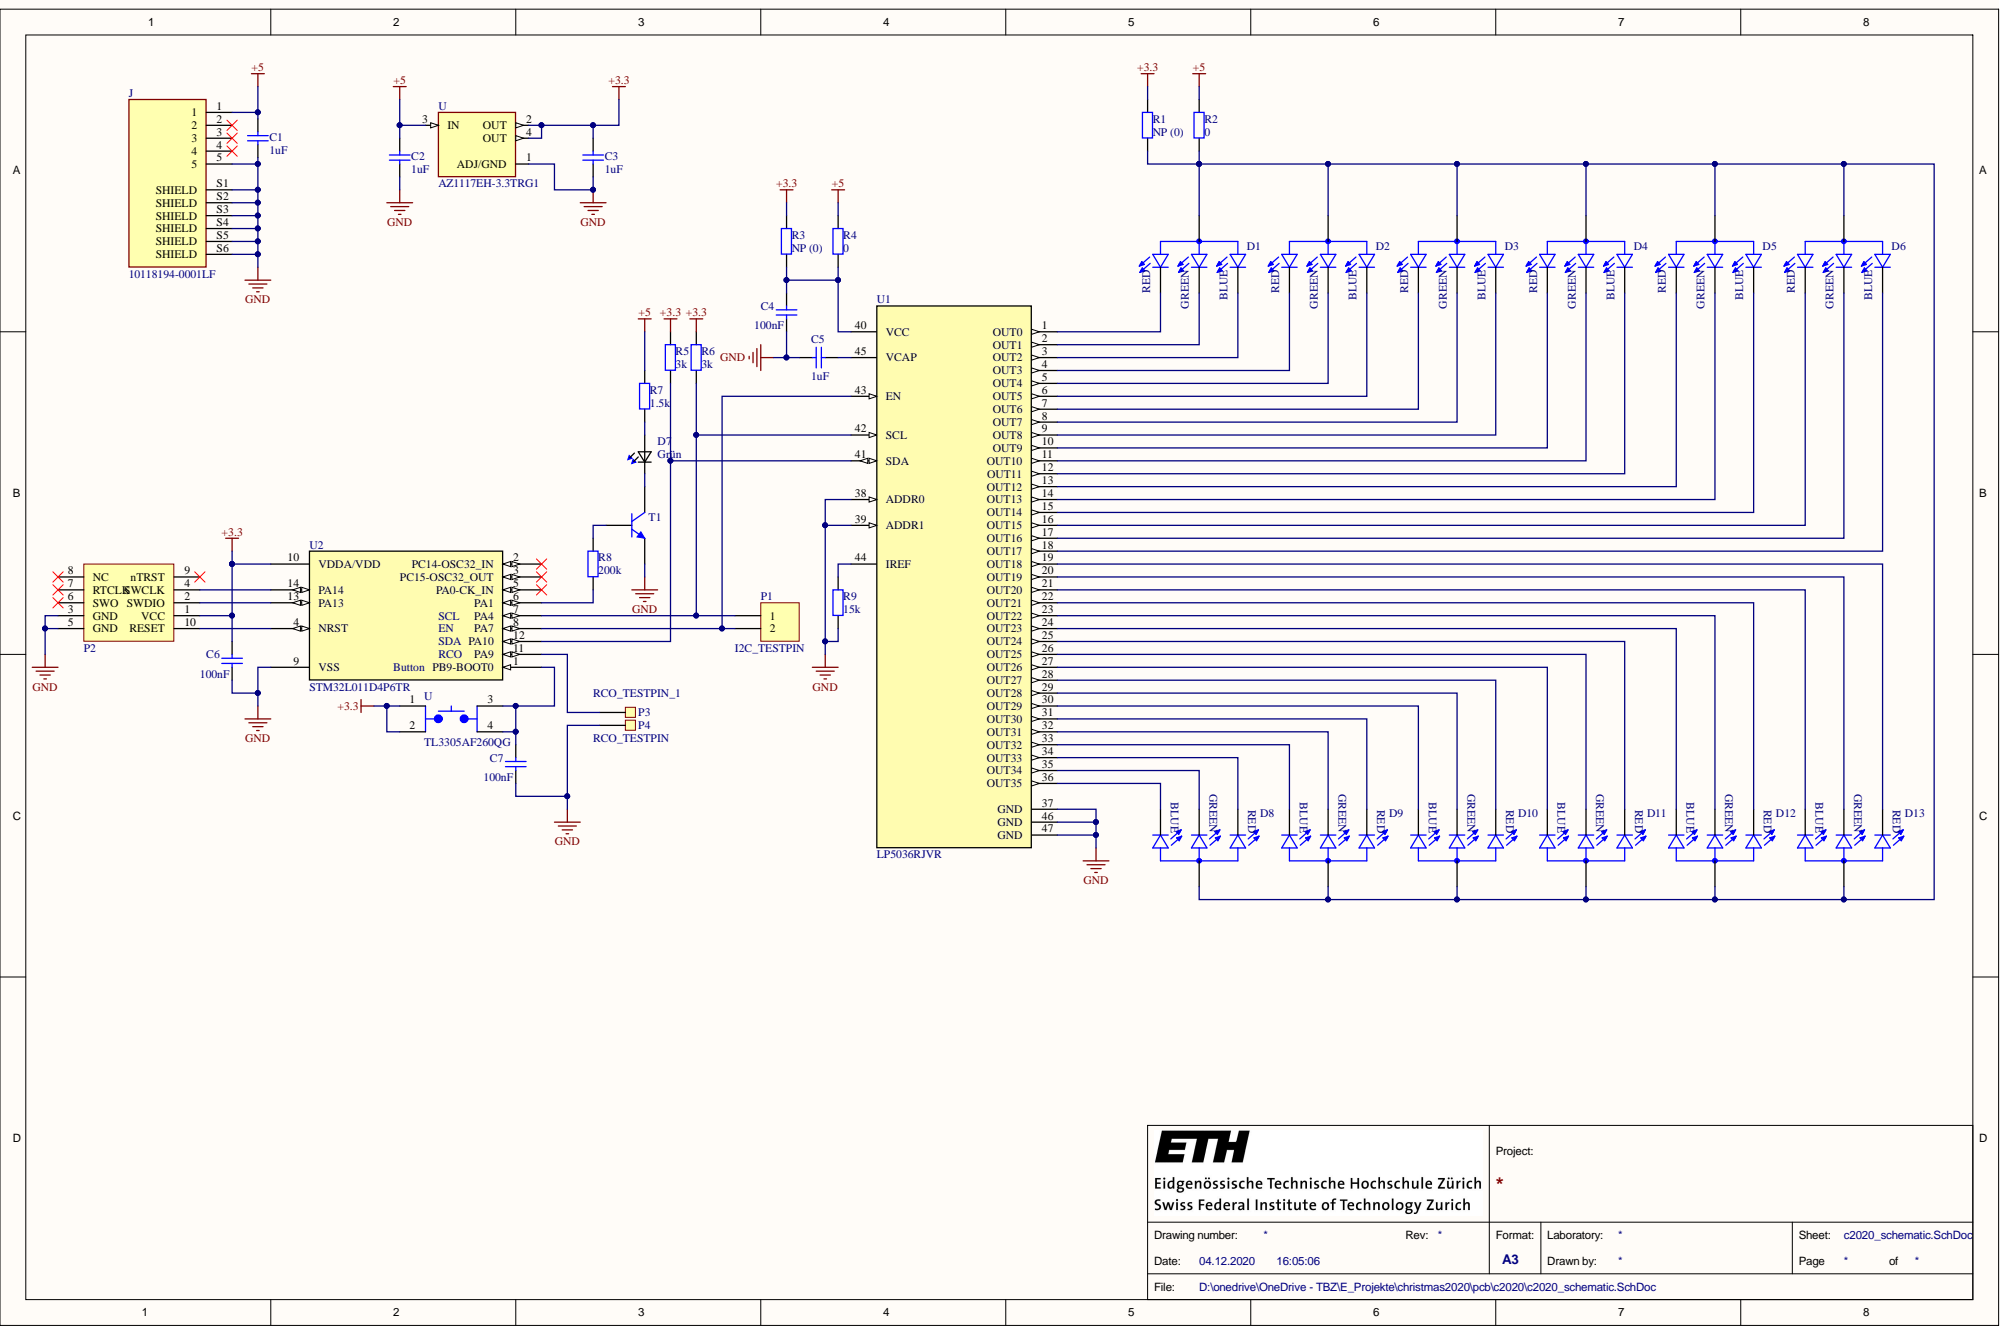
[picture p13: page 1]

D7 Grü | n | SDA 41

ADDR0 38

Pro jec t : *

Dra w i n g n u m ber : * Rev: * Dat e : 04. 12. 202 0 16: 05: 0 6 | For m a t : A 3 | Labor ato ry : * Dra w n b y : * | S h eet : c20 20_ schemat ic. SchDo c Pag e * o f *

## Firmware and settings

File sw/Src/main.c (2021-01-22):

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
/* Includes ------------------------------------------------------------------*/
#include "main.h"
/* USER CODE BEGIN PD */
#define address 0b01111000

#define R 0
#define G 1
#define B 2

/* USER CODE END PD */

I2C_HandleTypeDef hi2c1;

void SystemClock_Config(void);
static void MX_GPIO_Init(void);
static void MX_I2C1_Init(void);
static void MX_NVIC_Init(void);
/* USER CODE BEGIN PFP */
void WRITE_I2C(uint8_t reg, uint8_t data);
void UPDATE_REGISTER(void);
void Init_FL3236A(void);
void LED(uint8_t LED, uint8_t color, uint8_t value);
void HAL_GPIO_EXTI_Callback(uint16_t GPIO_Pin);
void LED_MODE(uint8_t mode);
/* USER CODE END PFP */

/* USER CODE BEGIN 0 */

const uint8_t PWM_REG[12][3] = {{0x1,0x2,0x3},
						  {0x4,0x5,0x6},
						  {0x7,0x8,0x9},
						  {0xA,0xB,0xC},
						  {0xD,0xE,0xF},
						  {0x10,0x11,0x12},
						  {0x22,0x23,0x24},
						  {0x1F,0x20,0x21},
						  {0x1C,0x1D,0x1E},
						  {0x19,0x1A,0x1B},
						  {0x16,0x17,0x18},
						  {0x13,0x14,0x15}};

const uint8_t G_CONTROL_REG = 0x4A;
const uint8_t PWM_UPDATE_REG = 0x25;
const uint8_t SHUTDOWN_REG = 0x00;
const uint8_t RESET_REG = 0x4F;

volatile uint8_t state = 1;
/*const uint8_t SIN[180] = {0,1,2,4,5,7,8,10,11,13,14,15,16,18,19,20,21,22,23,24,25,26,27,27,28,28,28,29,29,29,29,29,29,28,28,28,27,27,26,25,24,23,22,21,20,19,18,16,15,14,13,11,10,8,7,5,4,2,1,0,
						  0,0,0,0,0,0,0,0,0,0,0,0,0,0,0,0,0,0,0,0,0,0,0,0,0,0,0,0,0,0,0,0,0,0,0,0,0,0,0,0,0,0,0,0,0,0,0,0,0,0,0,0,0,0,0,0,0,0,0,0,
						  0,0,0,0,0,0,0,0,0,0,0,0,0,0,0,0,0,0,0,0,0,0,0,0,0,0,0,0,0,0,0,0,0,0,0,0,0,0,0,0,0,0,0,0,0,0,0,0,0,0,0,0,0,0,0,0,0,0,0,0};
*/
const unsigned char SIN2[64] = { 0,0,0,1,2,4,5,7,8,10,11,13,14,15,16,18,19,20,21,22,23,24,25,26,27,27,28,28,28,29,29,29,29,29,29,28,28,28,27,27,26,25,24,23,22,21,20,19,18,16,15,14,13,11,10,8,7,5,4,2,1,0,0,0};
/* USER CODE END 0 */

/**
  * @brief  The application entry point.
  * @retval int
  */
int main(void)
{
  /* MCU Configuration--------------------------------------------------------*/

  /* Reset of all peripherals, Initializes the Flash interface and the Systick. */
  HAL_Init();

  /* Configure the system clock */
  SystemClock_Config();

  /* Initialize all configured peripherals */
  MX_GPIO_Init();
  MX_I2C1_Init();

  /* Initialize interrupts */
  MX_NVIC_Init();
  /* USER CODE BEGIN 2 */
  HAL_GPIO_WritePin(I2C_EN_GPIO_Port,I2C_EN_Pin, GPIO_PIN_SET);

  if(HAL_I2C_IsDeviceReady(&hi2c1, address, 2, 10) == HAL_OK)
  {
	HAL_GPIO_WritePin(LED_GPIO_Port,LED_Pin,GPIO_PIN_SET);
	HAL_Delay(200);
	HAL_GPIO_WritePin(LED_GPIO_Port,LED_Pin,GPIO_PIN_RESET);
  }
  else
  {
	HAL_GPIO_WritePin(LED_GPIO_Port,LED_Pin,GPIO_PIN_SET);
	HAL_Delay(200);
	HAL_GPIO_WritePin(LED_GPIO_Port,LED_Pin,GPIO_PIN_RESET);
	HAL_Delay(200);
	HAL_GPIO_WritePin(LED_GPIO_Port,LED_Pin,GPIO_PIN_SET);
	HAL_Delay(200);
	HAL_GPIO_WritePin(LED_GPIO_Port,LED_Pin,GPIO_PIN_RESET);
  }

  uint8_t counter = 0;
  uint8_t oldstate = 0;
 /* WRITE_I2C(PWM_REG[7][0],64); //LED8 BLAU, PWM=64
  WRITE_I2C(CONTROL_REG[7][0], 0b111); //LED8 BLAU, IMAX/4 & LED ON

  UPDATE_REGISTER();*/

  Init_FL3236A();

/*
    uint8_t reset[2] = {0x4F, 0x00};
	HAL_I2C_Master_Transmit(&hi2c1, address, reset, 2, 10);

  	uint8_t newData[2] = {0x01, 64};
  	HAL_I2C_Master_Transmit(&hi2c1, address, newData, 2, 10);

  	uint8_t newData2[2] = {0x26, 0x07};
  	HAL_I2C_Master_Transmit(&hi2c1, address, newData2, 2, 10);

  	uint8_t newData3[3] = {0x25, 0x00};
  	HAL_I2C_Master_Transmit(&hi2c1, address, newData3, 2, 10);
*/

  /* USER CODE END 2 */

  /* Infinite loop */
  /* USER CODE BEGIN WHILE */
  while (1)
  {
	 if(state != oldstate)
	 {
		 for(counter = 1; counter != 13; counter++)
		 {
			 LED(counter,R,0);
			 LED(counter,G,0);
			 LED(counter,B,0);
		 }
		 oldstate = state;
	 }
	 LED_MODE(state);
	 HAL_Delay(100);
	  /*if(HAL_GPIO_ReadPin(BUTTON_GPIO_Port,BUTTON_Pin))
	  {
		  HAL_GPIO_WritePin(LED_GPIO_Port,LED_Pin,GPIO_PIN_SET);
	  }
	  else
	  {
		 // HAL_GPIO_WritePin(LED_GPIO_Port,LED_Pin,GPIO_PIN_RESET);
	  }*/
    /* USER CODE END WHILE */

    /* USER CODE BEGIN 3 */
  }
  /* USER CODE END 3 */
}

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
/* USER CODE BEGIN 4 */

void LED_MODE(uint8_t mode)
{
	static uint8_t i[12] = {15,40,50,10,25,5,30,0,35,55,20,45};

	uint8_t counter = 0;
	//static uint8_t LEDvalues = 0;

	switch(mode)
	{
		case 1:

			LED(2,R,SIN2[i[2-1]]);
			LED(4,R,SIN2[i[4-1]]);
			LED(7,R,SIN2[i[7-1]]);
			LED(11,R,SIN2[i[11-1]]);

			LED(5,G,SIN2[i[5-1]]);
			LED(1,G,SIN2[i[1-1]]);
			LED(9,G,SIN2[i[9-1]]);
			LED(12,G,SIN2[i[12-1]]);

			LED(8,B,SIN2[i[8-1]]);
			LED(3,B,SIN2[i[3-1]]);
			LED(6,B,SIN2[i[6-1]]);
			LED(10,B,SIN2[i[10-1]]);
			break;
		case 2:
			for(counter = 1; counter != 13; counter++)
			{
				LED(counter,R,20);
				LED(counter,G,16);
			}
			break;
		case 3:
			for(counter = 1; counter != 13; counter++)
			{
				LED(counter,R,30);
			}
			break;
		case 4:
			for(counter = 1; counter != 13; counter++)
			{
				LED(counter,G,30);
			}
			break;
		case 5:
			for(counter = 1; counter != 13; counter++)
			{
				LED(counter,B,30);
			}
			break;
			//LED(1,R,);
	}

	for(counter = 0; counter != 12; counter++)
	{
		if(i[counter]>=63)
		{
			i[counter] = 0;
		}
		else
		{
			i[counter]++;
		}
	}

	UPDATE_REGISTER();
}

void HAL_GPIO_EXTI_Callback(uint16_t GPIO_Pin)
{
	if(GPIO_Pin == BUTTON_Pin)
	{
		volatile int i = 0;
		for(i=0; i != 50000; i++);
		//HAL_GPIO_TogglePin(LED_GPIO_Port,LED_Pin);
		if(state >= 5)
		{
			state = 1;
		}
		else
		{
			state++;
		}
	}
}

void UPDATE_REGISTER(void)
{
	WRITE_I2C(PWM_UPDATE_REG,0x00);
}

void WRITE_I2C(uint8_t reg, uint8_t data)
{
	uint8_t newData[2] = {reg, data};

	HAL_I2C_Master_Transmit(&hi2c1, address, newData, 2, 10);
}

void LED(uint8_t LED, uint8_t color, uint8_t value)
{
	if(LED == 0) LED++;
	if(color > 2) color = 2;
	if(value > 30) value = 30;

	WRITE_I2C(PWM_REG[LED-1][color], value);
}

void Init_FL3236A(void)
{
	uint8_t i = 0;
	uint8_t data[2];

	data[0] = 0x4F;
	data[1] = 0x00;
	HAL_I2C_Master_Transmit(&hi2c1, address, data, 2, 10);
	//IS_IIC_WriteByte(Addr_VCC,0x25,0x00);//update PWM & congtrol registers

	HAL_Delay(500);

	data[0] = 0x4A;
	data[1] = 0x00;
	HAL_I2C_Master_Transmit(&hi2c1, address, data, 2, 10);
	//IS_IIC_WriteByte(Addr_VCC,0x25,0x00);//update PWM & congtrol registers

	data[0] = 0x00;
	data[1] = 0x01;
	HAL_I2C_Master_Transmit(&hi2c1, address, data, 2, 10);
	//IS_IIC_WriteByte(Addr_VCC,0x00,0x01);//normal operation

	data[1] = 0x7;
	for(i=0x26;i<=0x49;i++)
	{
		data[0] = i;
		HAL_I2C_Master_Transmit(&hi2c1, address, data, 2, 10);
		//IS_IIC_WriteByte(Addr_VCC,i,0xff);//turn on all LED
	}

	data[1] = 0x00;
	for(i=0x01;i<=0x24;i++)
	{
		data[0] = i;
		HAL_I2C_Master_Transmit(&hi2c1, address, data, 2, 10);
		//IS_IIC_WriteByte(Addr_VCC,i,0x00);//write all PWM set 0x00
	}

	data[0] = 0x25;
	data[1] = 0x00;
	HAL_I2C_Master_Transmit(&hi2c1, address, data, 2, 10);
	//IS_IIC_WriteByte(Addr_VCC,0x25,0x00);//update PWM & congtrol registers


	/*data[0] = 0x4B;
	data[1] = 0x01;
	HAL_I2C_Master_Transmit(&hi2c1, address, data, 2, 10);
	//IS_IIC_WriteByte(Addr_VCC,0x4B,0x01);//frequency setting 22KHz*/


	HAL_Delay(100);

	/*data[1] = 30;
	for(i=0x01;i<=0x24;i++)
	{
		data[1] = 90;
		data[0] = 0x19;
		HAL_I2C_Master_Transmit(&hi2c1, address, data, 2, 10);
		//IS_IIC_WriteByte(Addr_VCC,i,0x00);//write all PWM set 30

		data[0] = 0x25;
		data[1] = 0x00;
		HAL_I2C_Master_Transmit(&hi2c1, address, data, 2, 10);
		//IS_IIC_WriteByte(Addr_VCC,0x25,0x00);//update PWM & congtrol registers

		HAL_Delay(100);
	}*/


}
/* USER CODE END 4 */
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


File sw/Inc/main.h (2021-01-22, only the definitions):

#define BUTTON_Pin GPIO_PIN_9
#define BUTTON_GPIO_Port GPIOB
#define BUTTON_EXTI_IRQn EXTI4_15_IRQn
#define LED_Pin GPIO_PIN_1
#define LED_GPIO_Port GPIOA
#define I2C_EN_Pin GPIO_PIN_7
#define I2C_EN_GPIO_Port GPIOA

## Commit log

2020-12-23 added gerber
2021-01-22 Doku + SW
    [sw Debug.cfg, sw Run.cfg]

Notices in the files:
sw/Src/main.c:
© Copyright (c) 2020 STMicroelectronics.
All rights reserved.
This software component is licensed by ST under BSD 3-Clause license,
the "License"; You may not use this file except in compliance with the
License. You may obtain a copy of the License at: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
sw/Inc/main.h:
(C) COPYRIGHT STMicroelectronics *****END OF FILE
